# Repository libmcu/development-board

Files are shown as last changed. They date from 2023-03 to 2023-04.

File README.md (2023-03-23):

[한국어](./README_kr.md)

[https://libmcu.org/madi](https://libmcu.org/madi)

Boards produced by libmcu are divided into core boards and extension boards.

Several types of core boards are manufactured in the same form factor,
30x21.59mm long. Because data communication and debugger connection are
possible through the Type-C USB port of the core board, the core board by
itself can fully play the role of a development board.

Extention board is a board to which various sensors and functions are added.
A suitable core board can be attached/detached to the extension board.

For specifications, please refer to [the developer
documentation](https://docs.libmcu.org/boards/index.html).
[SDK](https://github.com/libmcu/MADI) and [getting started
guide](https://docs.libmcu.org/quickstart/index.html) are for you to get
started easily.

## Core Boards
Currently, there are three types of core boards using
[ESP32S3](https://docs.libmcu.org/boards/esp32.html#esp32-libmcu),
[STM32G4](https://docs.libmcu.org/boards/stm32.html#stm32-libmcu), and
[nRF52840](https://docs.libmcu.org/boards/nrf52.html#nrf52-libmcu).

## Extension Boards
Working on it.

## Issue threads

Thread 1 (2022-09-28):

USB-C 포트에 JTAG 핀을 추가하라

onkwon, 2022-09-28:
- SWDIO, SWCLK, SWO, NRST 핀 빼기
- ESP32 의 경우 SWD를 지원하지 않음
  - TMS(SWDIO)와 TCLK(SWCLK) + TDI, TDO 핀을 빼야함

## 참고자료
### USB 일반
- [USB2 사양](https://www.usb.org/document-library/usb-20-specification), [USB3.1 사양](https://manuais.iessanclemente.net/images/b/bc/USB_3_1_r1.0.pdf), [USB4 사양](https://www.usb.org/document-library/usb4r-specification)
- https://www.usb.org/sites/default/files/USB_TCPCI_R2_V1p3_30122_CLEAN.pdf
- https://www.usb.org/sites/default/files/USB%20Type-C%20Spec%20R2.0%20-%20August%202019.pdf
- https://en.wikipedia.org/wiki/USB-C
- https://www.ti.com/lit/wp/slyy109b/slyy109b.pdf
### Debug Accessory Mode
- https://hackaday.com/2022/02/24/an-unbusy-usb-c-port-doubles-up-for-jtag-programming/
- https://threadreaderapp.com/thread/1495860045728395278.html
### Alternate Mode(SBU 기반)
- https://www.ti.com/lit/wp/slly021/slly021.pdf
- https://forum.contextualelectronics.com/t/debugging-through-a-usb-type-c-connector-only/4615
- https://chromium.googlesource.com/chromiumos/platform/ec/+/refs/heads/release-R67-10575.B/board/servo_micro/ccd.md
### Type-C
- https://www.embedded.com/usb-type-c-and-power-delivery-101-ports-and-connections/

Wizmik187, 2022-09-28:
위 자료에 따르면 코어보드에 아래와 같은 OPAMP 회로, AND gate, MUX 회로가 들어가야 합니다.
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

현실성이 좀 없다는 생각이 드네요.

Wizmik187, 2022-09-28:
SBU1, SBU2 핀이라고, Audio accessary 를 위한 핀이 있기는 한데 이 2핀을 뺄 수는 있을 것 같아요. 검토 해보고 알려드리죠.

onkwon, 2022-09-28:
위 자료에서도 그랬듯이 코어가 아니라 중간에 어댑터 보드를 만들어 넣어야 하지 않을까요?

Wizmik187, 2022-09-28:
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
요런 형태로 확인됩니다.

코어보드의 SWD 핀들을 일반적인 USB host에 연결했을 때, 영향이 없도록하기 위해서. DAP 모드에 들어갔을 때만 SWD 핀들이 USB C 핀에 연결되게 하기 위함.

onkwon, 2022-09-28:
아, USB로부터 SWD 핀에 데미지가 갈까봐 있는거군요.

Wizmik187, 2022-09-28:
https://forum.contextualelectronics.com/t/debugging-through-a-usb-type-c-connector-only/4615
https://www.sparkfun.com/products/retired/14746

SBU 핀을 통한 디버깅 (구글 크롬 OS에서 사용했다고 함)

Wizmik187, 2022-09-28:
SWDIO
SWCLK
요 두핀만 빼도 디버깅 하는데 문제는 없을까요?
리셋핀이 없을 때 불편하다던가 하는..

onkwon, 2022-09-28:
SWDIO, SWCLK, SWO, NRST 네 핀 모두 있으면 가장 좋긴하죠.

리셋은 실제로 SWD 만으로 가능한데, "connect under reset" 를 지원해야 할 경우 문제가 있을지도 모르겠어요.

그래서 최선은 4핀 모두, 차선은 SWDIO, SWCLK, SWO 3핀, 정 안되면 SWDIO, SWCLK 두핀으로 가면 좋을 것 같아요.

onkwon, 2022-09-28:
위 자료와 USB 사양을 읽어보고 있는데요,

SuperSpeed 를 사용하지도 않고 USB4 기능을 사용하지도 않으니 호스트에서 RX 핀을 건드릴 일이 없을 것이고 그럼 SWD 핀에 데미지가 갈 일도 없을 것 같습니다. 그러니까 자료에 있는 추가 회로를 생략하고 어댑터 보드만 추가하는 방향으로 가는 것도 괜찮은 방법일 것 같습니다.

Wizmik187, 2022-10-10:
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

- RX 4핀에 디버깅 핀 할당
- SBU1, 2 핀으로 어댑터보드 방향 알려주기 (LED 연결)

onkwon, 2022-10-10:
[USB Type-C 스펙](https://www.usb.org/sites/default/files/USB%20Type-C%20Spec%20R2.0%20-%20August%202019.pdf) Appendix. B 절을 읽은 내용을 요약하면:

- Debug Accessory Mode 로 들어가려면 CC 두 핀 모두 풀업이거나 풀다운이어야 함
- 문제는 Type-C 케이블에 CC 라인이 들어가 있지 않음
- 따라서 직접 연결하거나 captive 디바이스여야 함
- 아래 그림처럼 노란색 핀은 자유롭게 사용할 수 있음
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

그래서 제 생각을 정리하면:
- 우리는 어댑터 보드를 사용하므로 케이블 문제는 고려사항이 아님
  - 개발보드 - 어댑터보드 - PC 직접 연결하기 때문
- 위 그림의 노란색 핀을 자유롭게 사용할 수 있으므로 커넥터 방향에 자유로울 수 있도록 여분의 tx/rx 핀을 모두 활용하면 어떨까 싶어요
- 그리고 사실 개발보드와 어댑터보드는 핀을 모두 연결하더라도 어댑터보드에서 PC로 가는 핀은 데이터 핀만 연결해도 상관없잖아요?
- 이런식으로 연결해서 사용하면 될 것 같은데, 어떻게 생각하시나요? : https://www.reddit.com/r/embedded/comments/syihdl/comment/hxy10b9

Wizmik187, 2022-10-10:
https://itecnotes.com/electrical/electronic-usb-c-debug-accessory-mode-and-usb-2-0/

onkwon, 2022-10-10:
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

- 우리는 그림과 같은 구성이니까 존이 공유한 링크에서 말한 우리 Core 보드(TS)는 compliant final product 가 될거고,
- 어댑터보드의 왼쪽(TS와 연결되는 쪽)은 DTS 역할로 CC 라인을 조작
- 어댑터보드의 오른쪽(PC와 연결되는 쪽)은 다시 CC 라인을 조작하지 않는 정상적인 포트로 사용하면 되지 않을까요?
  - 이 때 굳이 다른 JTAG 라인을 연결할 필요도 없을 것 같고요. 이 포트는 USB2.0 기능만 사용할테니 D+ D-만 연결해도 될 것 같아요

제가 뭔가 놓친게 있을까요?

Wizmik187, 2022-10-11:
DTS (어댑터 보드) 에서 CC 라인 2개를 모두 Pull-up 하면 TS (코어보드) 에서 DTS 가 연결되었다는 것을 인식하고, MUX 등을 이용하여 안쓰는 USB C 커넥터 핀에 SWD 핀이 연결되도록 하는 것이 정석일것 같습니다.  (제일 처음 봤던 아래 링크 문서처럼)
(https://hackaday.com/2022/02/24/an-unbusy-usb-c-port-doubles-up-for-jtag-programming/)

단, 이 경우엔 MUX  등의 불필요한 부품이 코어보드에 추가 되는 것이 문제이죠.

DAM 에서는 Host (PC 등)에 연결되는 상황을 정의하지는 않는 것 같아요. 사용자 몫인 것이죠.
DTS 없이 TS(코어보드) 를 바로 Host에 연결했을 때가 걱정되는 것이죠.

- MUX 등 부품을 추가하여 안전하게 간다.
- 왠만해서는 RX 핀을 안건드릴 거라고 가정하고, RX 핀에 SWD 핀을 할당한다.
- reversible 을 위하여  RX, TX 핀에 SWD  핀을 할당한다. 단 이 경우 위보다 문제가 생길 확률이 높음.

Wizmik187, 2022-10-11:
일반적인  USB C 케이블은 CC 핀 하나가 케이블에서 풀다운 되어 있기 때문에, CC 핀 2개 모두가 풀업되는 경우는 없습니다.
DTS (어댑터 보드)에서 DAM 을 위해 CC 핀 2개를 강제로 풀업시켜서, 지금 연결되는게 DTS이다 라고 TS에게 알려주는 것이죠.

Wizmik187, 2022-10-11:
USB 3.0 이상에서 추가되는 rx 핀이 host에 연결되지 않도록 USB 2.0 케이블만 사용하도록 가이드를 주는 방법이 가장 현실적일것 같습니다.

Wizmik187, 2022-10-12:
아래와 같은 방법 어떠신가요.

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

1. 아날로그 스위치 IC 를 사용하여 nRESET, SWDIO, SWO, SWCLK 4핀을 on / off 할수 있게 합니다.
2. USB C 커넥터의 SBU2 핀을 아날로그 스위치의 Control 핀에 연결하고,
3. 어댑터 보드가 꼽히면 SBU2 핀에 5V를 공급하게 해서 아날로그 스위치 IC를 on 시켜서 4핀을 연결시킵니다.

SBU1 SBU2 핀은
https://www.usb.org/sites/default/files/USB%20Type-C%20Spec%20R2.0%20-%20August%202019.pdf
위 링크의 아래 절 참조
- 4.3 Sideband Use (SBU)
- Table A-1 USB Type-C Analog Audio Pin Assignments

Audio Adapter Accessory Mode 에서 MIC / AGND 로 쓰이므로 host 에서 별다른 영향을 주지는 않을 것으로 보입니다.

onkwon, 2022-10-13:
좋습니다! 말씀하신대로 하면 핀 대칭도 유지할 수 있겠네요. 👍

onkwon, 2022-10-13:
그런데 다른 회로들을 좀 찾다보니 SWO 보다 Vref 핀을 빼는게 정석(?)인가 싶네요?

Wizmik187, 2022-10-13:
쿤,
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

ESP32 는 JTAG는 지원하는데 SWD를 지원하지 않는다는다네요...

JTAG는 TDI, TDO, TCK, TMS 총 4핀에 reset 까지 5핀이 필요한것 같습니다..

onkwon, 2022-10-13:
네, 이슈 description 에 업데이트 해두었었는데, 앞으로 업데이트할 때 따로 알림을 해야겠네요.

저는 커넥터 좌우 대칭을 유지하고 싶고, 스위치 IC에 여분 핀도 없으니 ESP32 의 경우는 reset 을 빼고 가면 어떨까 싶습니다.

onkwon, 2022-10-13:
핀 아웃은 아래 이미지처럼 하면 어떨까요? 검색해보니 JLink edu mini 와 ULinkPro pinout 이 같더라고요.

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

- https://www.segger.com/products/debug-probes/j-link/models/j-link-edu-mini/
- https://developer.arm.com/documentation/101416/0100/Hardware-Description/Target-Interfaces/Cortex-Debug--10-pin-

onkwon, 2022-10-18:
존, 이건 정리된 것 같으니 이슈 닫을게요. 필요하시면 다시 열어주세요.

Closed 2022-10-18.

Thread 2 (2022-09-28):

코어보드의 소자 소비전류, 정확도, 가격을 파악하라

onkwon, 2022-09-28:
- BQ25180YBGR
  - https://www.ti.com/lit/ds/symlink/bq25180.pdf
- TMP103BYFFR
- APA102-2020

onkwon, 2022-10-18:
## BQ25180

### 사양

| FUNC | MIN | TYP | MAX | UNIT |
| ----- | ---- | ----- | ----- | ----- |
| Input Voltage | -0.3 | | 25 | V |
| Voltage | -0.3 | | 5.5 | V |
| Input Current | | | 1.1 | A |
| SYS Discharge Current | | | 1.5 | A |
| Output Sing Current | | | 20 | mA |
| VBAT | 2.2   | | 4.6   | V       |
| VIN    | 2.7    | | 5.5   | V      |
| Tj*     | -40  | | 125  | C       |
| Quiescent Current(VIN) | | 0.75 | 1 | mA |
| Quiescent Current(BAT) | | 4 | 5 | uA |

- Tj*: Operating Junction Temperature Range

### 노트
- 배터리 완전 방전을 방지하기 위해 `CHARGERCTRL1` 레지스터의 `BUVLO` 비트를 설정해야 함
- overvoltage protection 기능도 있음. 입력전압에 대한 상대값이기 때문에 디폴트 유지하기로
- `IBAT_OCP` 레지스터에 배터리 overcurrent 설정할 것
- Safety timer 를 활용하면 사용자에게 알람 줄 수 있음
  - INT 핀 MCU 에 연결했는지 확인
- Thermal protection 기능 좋아 🥹

### 할일
- [ ] 리셋핀을 MCU 에서 빼지말고 BQ25180 TS/MR 핀
활용하면 어떨지
  - 다른 버튼 하나는 MCU GPIO 핀을 연결할 수 있고
  - MCU 뿐만 아니라 시스템 전체가 리셋됨
  - 소비젼류가 늘어나는 문제가 있지만, 저전력이 중요한 제품에서는 해당 기능을 끄는 방법이 있겠음
  - 또 하나의 문제는 300ms latency 가 발생하는 건데, 리셋은 보통 개발단계에서만 사용될 것이기 때문에 괜찮지 않을까 싶음
- [ ] 배터리 용량 결정하고, 충전 및 방전 시간 명시

Wizmik187, 2022-10-19:
@onkwon 그럼 MCU 리셋 버튼이 없을텐데요? 괜찮을까요?

onkwon, 2022-10-19:
버튼에 TS/MR 핀을 연결하고

- 300ms 이상 누르면 MCU soft reset
- 5초 이상 누르면 시스템 전체 hard reset

이렇게 가면 어떨까요?

Wizmik187, 2022-10-19:
이해했습니다. 좋은생각인 것 같아요. 단 펌웨어 드라이버에서 버튼 컨트롤하는 부분이 들어가야할것 같습니다. 데이터시트를 좀더 읽어보고 회로 결정할게요.

onkwon, 2022-10-19:
> [...] 펌웨어 드라이버에서 버튼 컨트롤하는 부분이 들어가야할것 같습니다. [...]

어떤 컨트롤을 말씀하시는 건가요? 아래 이미지처럼 기존 회로에서 다른 변경없이 MR 핀에 nRESET 만 엮어주면 되지 않나요?

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

onkwon, 2022-10-23:
@Wizmik187
현재 MR 핀을 어떻게 연결할지 두가지 안이 있는데요:
1. *사용자 버튼*에 연결(MCU GPIO 핀과 함께 연결)
2. *Reset 버튼*에 연결

저는 2번을 선호해요. 제 논리는 아래와 같습니다:
- *MCU 리셋* 이든 *시스템 리셋* 이든 리셋은 리셋 버튼으로 이루어져야 한다고 봄
  - 시스템 리셋을 위해 *리셋 버튼*이 아니라 *사용자 버튼*을 누른다는 게 직관적이지 않음
  - MR 핀의 시스템 리셋과 *사용자 버튼*의 custom 기능이 충돌할 수 있음
    - 이런 사용자 고려사항들은 없을수록(단순할수록) 좋다고 보임
    - 그리고 충돌을 피하기 위해 시스템 리셋의 홀드시간을 늘리는 것도 사용자 편의를 크게 감수해야 함
- *사용자 버튼*은 이미 MCU 의 GPIO 에 연결되어 있으므로 MR 핀으로 입력받은 short/long 버튼은 기능적으로 의미가 있어보이지 않음

Wizmik187, 2022-10-24:
쿤 말 듣고, Reset 핀에 연결하는 것도 나쁘지 않을 것 같다고 설득되긴 했는데요,

Reset 버튼이나 사용자 버튼에 MR핀을 같이 연결하기에는 아래와 같은 문제가 있을 것 같습니다.
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

데이터시트 그림에 따르면 bq25180이 MR 핀으로 계속 pulse 를 만들고 이 펄스로 버튼 누르는 시간을 감지하고 있는 것 같습니다. 즉 Reset 핀이나 GPIO에 이 펄스가 입력되면 MCU 오동작이 예상됩니다.

따라서 일단은 GPIO와 같이 물리는건 포기하고 처음에 얘기했던것 처럼 아래와 같이 저항으로 선택할 수 있게 하는게 어떨까 해요. (default 는 GPIO 연결)
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

onkwon, 2022-10-24:
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

타이밍 차트 표현이 헷갈리게 해놓은 것 같아요. 그런데 제가 이해하기론, 전력소비를 줄이기 위해 200ms 주기로 센싱한다는 것 같습니다. 그래서 여전히 2번을 주장해봅니다 😅

Wizmik187, 2022-10-25:
네 쿤 말씀이 맞는 것 같습니다. 그런데 추가로 걱정되는게 생겼습니다.

일단 기본적으로 Reset 핀에는 풀업이 달려있기 때문에(ESP의 경우  autoreset을 위해 1uF Cap 도 부착) , reset 핀을 MR 핀에 연결하는 순간 MR 핀에도 풀업이 달리게 되고, 이 경우 TS (NTC 연결하여 온도 측정) 하는 기능이 제 동작을 못할 수 있습니다.

최악의 상황에는 External NTC Monitoring (TS) 기능을 disable 해야 할수도 있을것 같습니다.

요 회로는 한번 TI community에 올려서 TI 쪽에 체크를 받아볼게요.

Wizmik187, 2022-10-25:
생각해보니 10KR풀업 저항과 10K NTC 가 달리는 순간 Reset 핀이 3.3/2 V 이 될 거고 리셋핀 동작이 제대로 안되겠네요.
reset 핀과 NTC와 같이 사용하기는 어려울것 같습니다.

쿤 말씀대로 0R 을 추가하는게 현실적이겠네요.

onkwon, 2022-10-25:
네, 내부 온도센서가 있기 때문에 제 생각에는 외부 온도센서를 붙이는 일이 보통은 없을 것 같거든요. 그래서 그런 케이스를 그렇게 비중을 두고 고려할 필요가 있을까 싶어요. 어떻게 생각하세요?

Wizmik187, 2022-10-25:
네 좋습니다.
짧게 누르면 MCU reset 길게 누르면 전체 하드웨어 리셋이 일관성이 있어서 좋을것 같습니다.

Ti support 에 문의했으니 회로적으로 문제 없는지 보겠습니다.

https://e2e.ti.com/support/power-management-group/power-management/f/power-management-forum/1164580/bq25180-able-to-place-pullup-resistor-to-mr-pin

onkwon, 2022-10-29:
뒷북이긴 한데, M5Stack 에는 어떤 IC를 썼나 궁금해져서 찾아봤습니다. [AXP192](https://github.com/m5stack/M5-Schematic/blob/master/Core/AXP192%20Datasheet_v1.1_en_draft_2211.pdf) 을 사용했는데, 가격이 깡패입니다: $0.35
따로 레귤레이터가 필요하지도 않구요.

onkwon, 2022-11-02:
정리된 내용이므로 이슈 닫겠습니다.

Closed 2022-11-02.

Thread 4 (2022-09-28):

코어보드 사양을 결정하라

onkwon, 2022-09-28:
## MCU
- [x] ESP32
  - ESP32-WROOM-32E-N4
  - [ESP32-WROOM-32E Datasheet](https://www.espressif.com/sites/default/files/documentation/esp32-wroom-32e_esp32-wroom-32ue_datasheet_en.pdf)
  - [ESP32 Series Datasheet](https://www.espressif.com/sites/default/files/documentation/esp32_datasheet_en.pdf)
  - https://www.espressif.com/en/products/modules
  - 안테나 때문에 비용에 따라 ESP32-WROVER-IE 를 고려해보는 것도
  - 100개 기준 $2.85
    - https://lcsc.com/product-detail/WiFi-Modules_Espressif-Systems-ESP32-WROOM-32E-N4_C701341.html
- [ ] ESP32-C3
- [ ] STM32
  - STM32G0 vs STM32G4
- [x] nRF52840
- [ ] nRF9160

## 디버깅 포트
SWDIO, SWCLK 두 핀으로 플래시를 비롯한 디버깅 기능은 문제없이 사용할 수 있음. 하지만 "connect under reset"(SWD 핀을 다른 용도로 사용할 경우) 를 지원해야 할 경우 문제. 이 때는 NRST 핀이 필요함. SWO 는 플러스 옵션.

- [x] SWDIO
- [x] SWCLK
- [x] SWO
- [x] NRST

## 온도센서
대게의 경우 SoC 에 내장된 온도센서가 하나씩 있음. ESP32 에만 없음(ESP32 C3/S3 에는 있음)

## 상태 LED

## 소비전류
TBD

## PMU
- [ ] BQ25180YBGR
  - https://www.ti.com/lit/ds/symlink/bq25180.pdf
- [ ] AXP202
  - https://dl.linux-sunxi.org/AXP/AXP202%20Datasheet_v1.0_en.pdf
  - https://github.com/tuupola/axp202
- [ ] AXP192
  - https://github.com/m5stack/M5-Schematic/blob/master/Core/AXP192%20Datasheet_v1.1_en_draft_2211.pdf

## 주변장치
- [x] ADC
- [x] UART
- [x] SPI
- [x] I2C
- [x] Timer(PWM)
- [ ] USB
- [ ] DMA
- [ ] QSPI

## 핀아웃(폼팩터)
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

### USB C

반대 방향과 대칭이므로 윗줄만 나타냄

| GND | TX1+ | TX1- | VBUS | CC1 | D+ | D- | SBU1 | VBUS | RX2- | RX2+ | GND |
| ----- | ----- | ----- | ----- | ----- | ---- | ---- | --- | ----- | ----- | ----- | ------ |
|          |           |          |           |           |        |          |  Target VCC  |          | SWDIO | SWCLK |    |

## ESP32 Core 보드 사양

| Name | Desc. |
| ------ | ----- |
| ESP32-WROOM-32E-N4(ESP32-D0WD-V3) | 240MHz dual core, 600 DMIPS, 520KB SRAM, Wi-Fi, BLE |
| Flash | 4MB |
| PSRAM | - |
| Input Voltage | 5V @ ?mA |
| Interface | TypeC |
| LED | Blue power indicator light |
| Button | Reset button, User button |
| PMU | BQ25180YBGR |
| USB Chip | CH9102F |
| Lithium Battery | ?mAh @ ?V |
| Antenna | 2.4GHz PCB antenna |
| Operating temperature | -40 ~ 85 (다른소자 확인필요) |
| Net Weight | |
| Gross Weight | |
| Product Size | |

onkwon, 2022-09-28:
언급된 MCU 중에 ESP32 에만 USB 가 없습니다.
uart_to_usb 칩은 외부로 빼는 방법이 있겠지만, 다른 보드와의 호환성이나 사용자 편의를 생각하면 내장하는 게 좋을 것 같습니다.

onkwon, 2022-10-18:
@Wizmik187 ESP32 HSPI vs VSPI 에서 저는 VSPI 핀만 뽑아도 충분할 것 같아요.

- 두개다 하드웨어 SPI 이고
- HSPI 가 JTAG 핀과 겹치기도 하고요

onkwon, 2022-10-18:
그리고 존이 말씀하셨듯이 주변장치 핀아웃은 "가능한" 모든 보드에서 호환되는 방향으로 가면 좋을 것 같아요.

Wizmik187, 2022-10-24:
아래 링크에 따르면 VSPI HSPI 간 속도차이가 있는 것 같고 HSPI 가 더 빠를것 같긴 한데요. 그래도 VSPI 를 빼는게 괜찮을까유?

https://www.youtube.com/watch?v=UUsP7u4vkN0&ab_channel=CoherentWave

Wizmik187, 2022-10-24:
- USB 다이오드 추가
- 커넥터 1x8 로 2개로 변경
- 바텀면 있는 소자를 전부 탑면으로 옮길 수 있는지 검토

onkwon, 2022-10-24:
VSPI 나 HSPI 나 기능상으로는 별다른 차이가 없어서 뭘 사용해도 상관없을 것 같은데, HSPI 가 JTAG 핀과 겹치니 VSPI 사용하면 좋을 것 같습니다.

Closed 2022-11-07.

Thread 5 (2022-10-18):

어댑터 보드를 설계하라

onkwon, 2022-10-18:
- 코어보드 디버깅을 용이하게 하는 추가 개발보드

## Future Work
- [ ] DAP 적용. JLink 와 같은 추가 디버거를 제거

onkwon, 2022-10-28:
GD32, APM32, AT32 시리즈에서 USB 디바이스를 내장하고 128KB 이상의 플래시와 32KB 이상의 SRAM 을 가진 MCU 중에서 재고가 있고 가격이 싼 걸 찾아봄:

- https://www.chipsmall.com/So/apm32f.html
- https://www.chipsmall.com/So/gd32f.html
- https://www.chipsmall.com/So/at32f.html

찾아본 것 중에는 APM32F103C8T6 이 가장 저렴한데, 메모리가 20K라 가능할지 모르겠음.
그리고 재고와 가격이 사이트마다 달라서 신뢰하기가 어려움

- [AT32F403ARCT7](https://www.chipmall.com/search?q=at32f403a&qty=&page=1)
  - 100개 기준 $2.33
- [APM32F103C8T6](https://www.chipsmall.com/Products/APM32F103C8T6_Geehy_20383477.html)
  - 100개 기준 $1.34
- [GD32F103C8T6](https://www.chipmall.com/search?q=gd32f103&qty=&page=1)
  - 100개 기준 $2.2

onkwon, 2022-10-28:
아래 칩 중 하나를 사용하면 어떨까 싶습니다. 가격이나 수급에 문제가 있다면 다른 대안을 또 찾아봐야겠지만.

- [GD32F103CBT6](https://www.gigadevice.com/products/microcontrollers/gd32/arm-cortex-m3/mainstream-line/gd32f103-series/gd32f103cbt6/)
- [GD32F103RBT6](https://www.gigadevice.com/products/microcontrollers/gd32/arm-cortex-m3/mainstream-line/gd32f103-series/gd32f103rbt6/)
- [GD32F103TBU6](https://www.gigadevice.com/products/microcontrollers/gd32/arm-cortex-m3/mainstream-line/gd32f103-series/gd32f103tbu6/)
- [GD32F103VBT6](https://www.gigadevice.com/products/microcontrollers/gd32/arm-cortex-m3/mainstream-line/gd32f103-series/gd32f103vbt6/)

onkwon, 2022-10-31:
## APM32 관련 노트
- 가격이나 용도를 생각하면 APM32E103Cxx6 이 적합해보이지만
  - 하위 모델은 일단 재고를 못찾겠음
- 재고와 추가적인 용도(Core 보드)에 함께 사용할 걸 생각하면 APM32E103RET6 가 괜찮은 선택으로 보임
- APM32F와 APM32E 차이점은 미세공정이 적용되었다고
  - 전류 소비가 절반?!이나 줄고
  - 최대 클럭은 1.7배 빠르다고
  - 그리고 FPU가 있음
- 국내 유통사: http://itechcorp.co.kr/

Wizmik187, 2022-11-03:
와우! 국내 유통사 까지 있네요. 좋습니다.

onkwon, 2022-11-03:
월요일에 국내 유통사로부터 샘플 3개 받기로 했습니다.
처음에 10개로 얘기가 됐었는데, 회사 정보가 없어서 그런지 소극적으로 대응하시네요.
첫 구매는 MOQ 250개 라고 합니다. 견적서를 아직 안보내줘서 정확한 가격은 모르겠구요.
대략 들은 가격은 $1.65 입니다.
아, APM32E103CET6 로 얘기가 됐습니다. LQFP48 입니다.

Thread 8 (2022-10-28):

회로를 리뷰하라

onkwon, 2022-10-28:
올려주신 회로보고 몇가지 의문사항 남겨요

## 1. 사용자 버튼은 빠지는 건가요?
공간상 넣기가 곤란하다면 스루홀? 형태로 하나 빼놓는 건 어떨까요?
## 2. 4.4v ~ 4.9v 범위의 전압을 VSYS 핀으로 내보내게 되는데 쓸모가 있을지 의문입니다
- VIN 을 넣는건 어떨까요?
- 지금은 전원 유입될 수 있는 곳이 USB 포트밖에 없어서 VIN이 있으면 활용 여지가 있을 것 같습니다
## 3. 아래 회로에서 SYS는 output 인데 input 심볼이 있는 것 같아요
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

Wizmik187, 2022-10-28:
1.
사용자 버튼은 바텀면 중앙에 위치시켰습니다. 자리만 있고 부품 실장은 안하려고 합니다. (SMT를 탑면만 하여 비용 절감)
사용자가 필요하다면 솔더링 하여 사용하는 것으로 생각하고 있어요.
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

바텀면 중앙이 버튼 위치로는 자연스러워서 위와 같이 했는데, 고민중이긴 합니다. 리셋버튼이랑 대칭되게 탑면에 배치할 수는 있을것 같아요.

마찬가지로 NTC도 자리만 있고 필요하다면 솔더링 하여 사용하도록 가이드 하려고 합니다.

2.
여러가지 상황을 고려했는데요, 일단은 헤더핀으로 사용하는 센서나 기타 주변기기에
전원을 공급해야 할때 SYS 전원을 사용할 수 있습니다. 3.3V LDO 는 최대 전류가 300mA라서 애매한 경우가 생길 수 있습니다. 3.3V 외의 다른 전압 (예를 들면 1.8V나 12V) 을 만들어야 할 때도, 3.3V 를 입력으로 넣는 것보다 SYS를 넣는 것이 더 효율적일것 같아요.

또한 외부에서 전원을 공급받을 때도, SYS핀을 통해 공급받는 것이 각종 bq25180 Safety feature 를 사용할 수 있을거라는 생각이 들어요.
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
위와 같이 세팅하면, VIN (USB 전원)이 존재해도 쫑안나고 안전하게 SYS핀을 통해 전원을 공급받을 수 있을듯 합니다.
(SYS 핀으로 전원을 공급하고 싶을 때는 SYS off floating 으로 세팅하도록 가이드)

3.
수정하였습니다!

onkwon, 2022-10-28:
## 1
- 저도 의견을 보태자면, 버튼은 탑면에 배치하고 실장하면 좋을 것 같습니다
- 그리고 배터리를 부착하게 되면 위치가 아마도 현재의 사용자 버튼 위치가 되지 않을까요?
- 그런 점에서 NTC 위치도 구석으로 좀 밀면 어떨까 싶기도 하고요

## 2
좋습니다. 👍 `SYS` 핀에 그런 기능이 있는지 몰랐네요. 하나 추가적으로 드는 의문이

- `SYS_MODE` 가 `00` 인 상태(Normal Operation)에서 SYS 로만 전원이 공급되는 경우에는 문제가 없을 것 같은데
- `SYS_MODE` 가 `00` 인 상태(Normal Operation)에서 IN 으로도 전원이 공급되고 SYS 로도 전원이 공급되는 경우에는 어떻게 동작하게 될까요?

왜냐하면 상시전원 제품이라고 가정하고, 전원을 넣은 상태에서 디버깅을 위해 USB 를 꽂아도 괜찮을까 라는 생각이 들었어요.

## spec.
spec. 정리를 위해 아는 것만 요약해보면

### 전원
- IN 입력 전압은 2.7 ~ 5.5VDC(최대값은 -0.3 ~ 25VDC)
- IN 최대 허용 전류는 1.1A
- [출력] SYS 최대 허용 전류는 1.5A
  - 순간(<20ms) 최대 허용 전류는 2.5A
- [입력] SYS 최대 입력 전압은 1.8 ~ 5.5VDC

### 온도
| 소자 | 온도(도섭씨) |
| ---- | ----------- |
| TCR3RM33A | -40 ~ 85 |
| BQ25180 | -40 ~ 125 |
| SN74LV4066ARGYR | -40 ~ 85 |
| CP2102N | -40 ~ 85 |
| KUSBX-SMT-CS2-B30TR | -30 ~ 85 |
|  ESP32-WROOM-32E | -40 ~ 85 |

PCB, 커넥터, 패턴등이 어떻게 되는지 모르지만, 일단은 권장 온도는 -30 ~ 85 도 라고 볼 수 있겠네요.

Wizmik187, 2022-10-31:
> * `SYS_MODE` 가 `00` 인 상태(Normal Operation)에서 SYS 로만 전원이 공급되는 경우에는 문제가 없을 것 같은데
> * `SYS_MODE` 가 `00` 인 상태(Normal Operation)에서 IN 으로도 전원이 공급되고 SYS 로도 전원이 공급되는 경우에는 어떻게 동작하게 될까요?

사실 이부분은 저도 추측으로 괜찮을 거 같다 라고 생각만 드는거라서, 정확히는 이렇게 사용해도 되는지 TI 쪽에 문의를 해보겠습니다.

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

일단 제 판단에는, FET로 전류제어하는 기능이 있기 때문에, SYS에 전원이 있는 상태에서 IN에 5V가 들어와도 어느 한쪽으로 스펙이상의 전류가 흘러서 IC가 망가지거나 하는 일은 없을 것 같긴 합니다.

onkwon, 2022-11-16:
더이상 관련 이슈가 없으므로 닫겠습니다.

Closed 2022-11-16.

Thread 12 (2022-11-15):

PMU IC 를 선정하라

onkwon, 2022-11-15:
## 요구사항
- [ ] 리튬 배터리 충전
- [ ] USB 공급전원에서 동작(3V ~ 12V 입력 전압 지원하면 좋음)
- [ ] 최소 300mA 공급, 가능한 800mA 이상
- [ ] lq(대기전류) 낮을수록 좋음. 최소 수십 uA보다 낮아야 함
- [ ] 배터리 잔량 체크
- [ ] MCU 구동을 위한 3.3V 출력

onkwon, 2022-11-23:
결정된 것 같으니 닫겠습니다.

Closed 2022-11-23.

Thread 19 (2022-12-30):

Core-S3 보드 브링업

onkwon, 2022-12-30:
## 점검항목
- [ ] 시리얼 플래시
- [ ] 콘솔
- [ ] LED
- [ ] BQ25180
- [ ] 와이파이
- [ ] 리셋 버튼
- [ ] 사용자 버튼
- [ ] 전원 노이즈
  - [ ] LDO
  - [ ] BMS
- [ ] 전압 레벨
  - [ ] LDO
  - [ ] BMS

onkwon, 2022-12-30:
@Wizmik187 [ESP32](https://github.com/libmcu/development-board/tree/main/core/Core_ESP32-WROOM-32E_PCB) 보드와 S3 보드의 I2C 포트가 다른데 통일하면 좋을 것 같아요.

ESP32 는 GPIO21, 22 사용했고, S3에서는 GPIO17, 18 사용하고 있습니다.

onkwon, 2022-12-30:
핀헤더 텍스트도 추가하는 게 좋을 것 같아요.
리셋버튼이 뭔지 사용자버튼이 뭔지 매번 헷갈리고,
배터리 연결을 위해 `+VBAT` 핀 찾기도 번거로운 것 같아요.

Wizmik187, 2022-12-30:
네 그런데 보드가 작다보니 넣는게 좀 애매하긴 해요. 지저분해보이기도 하고. 최대한 잘 넣어보겠습니다.

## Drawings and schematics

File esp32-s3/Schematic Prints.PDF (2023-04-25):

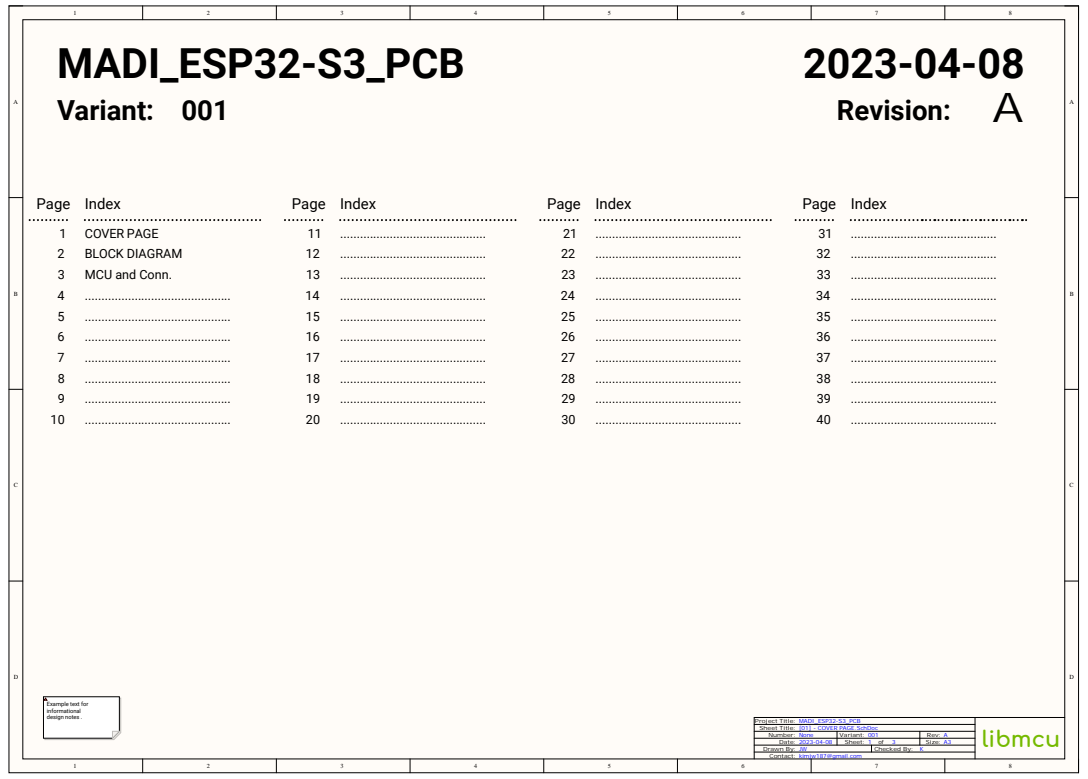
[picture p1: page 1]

Project Title:
Sheet Title: [01] - COVER PAGE.SchDoc

Number: None | Variant: 001 | Rev: A
Date: 2023-04-08 | Sheet: 1 of 3 | Size: A3
Drawn By: JW

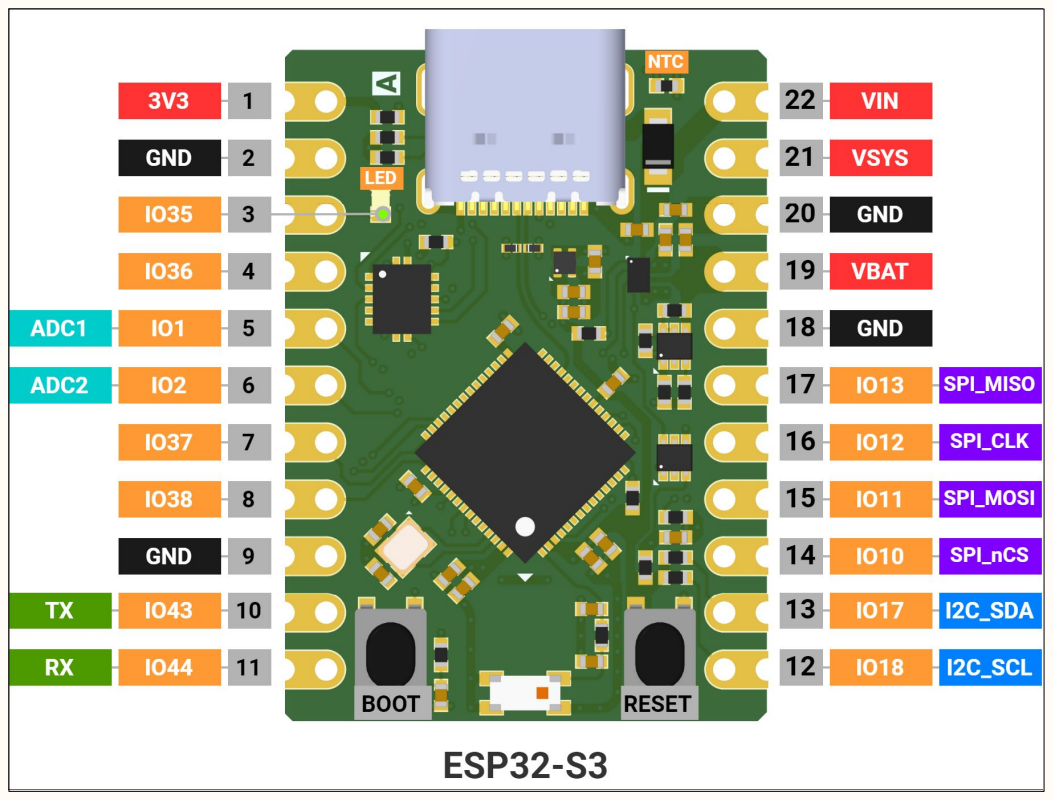
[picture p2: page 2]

Sheet Title: [02] - BLOCK DIAGRAM.SchDoc

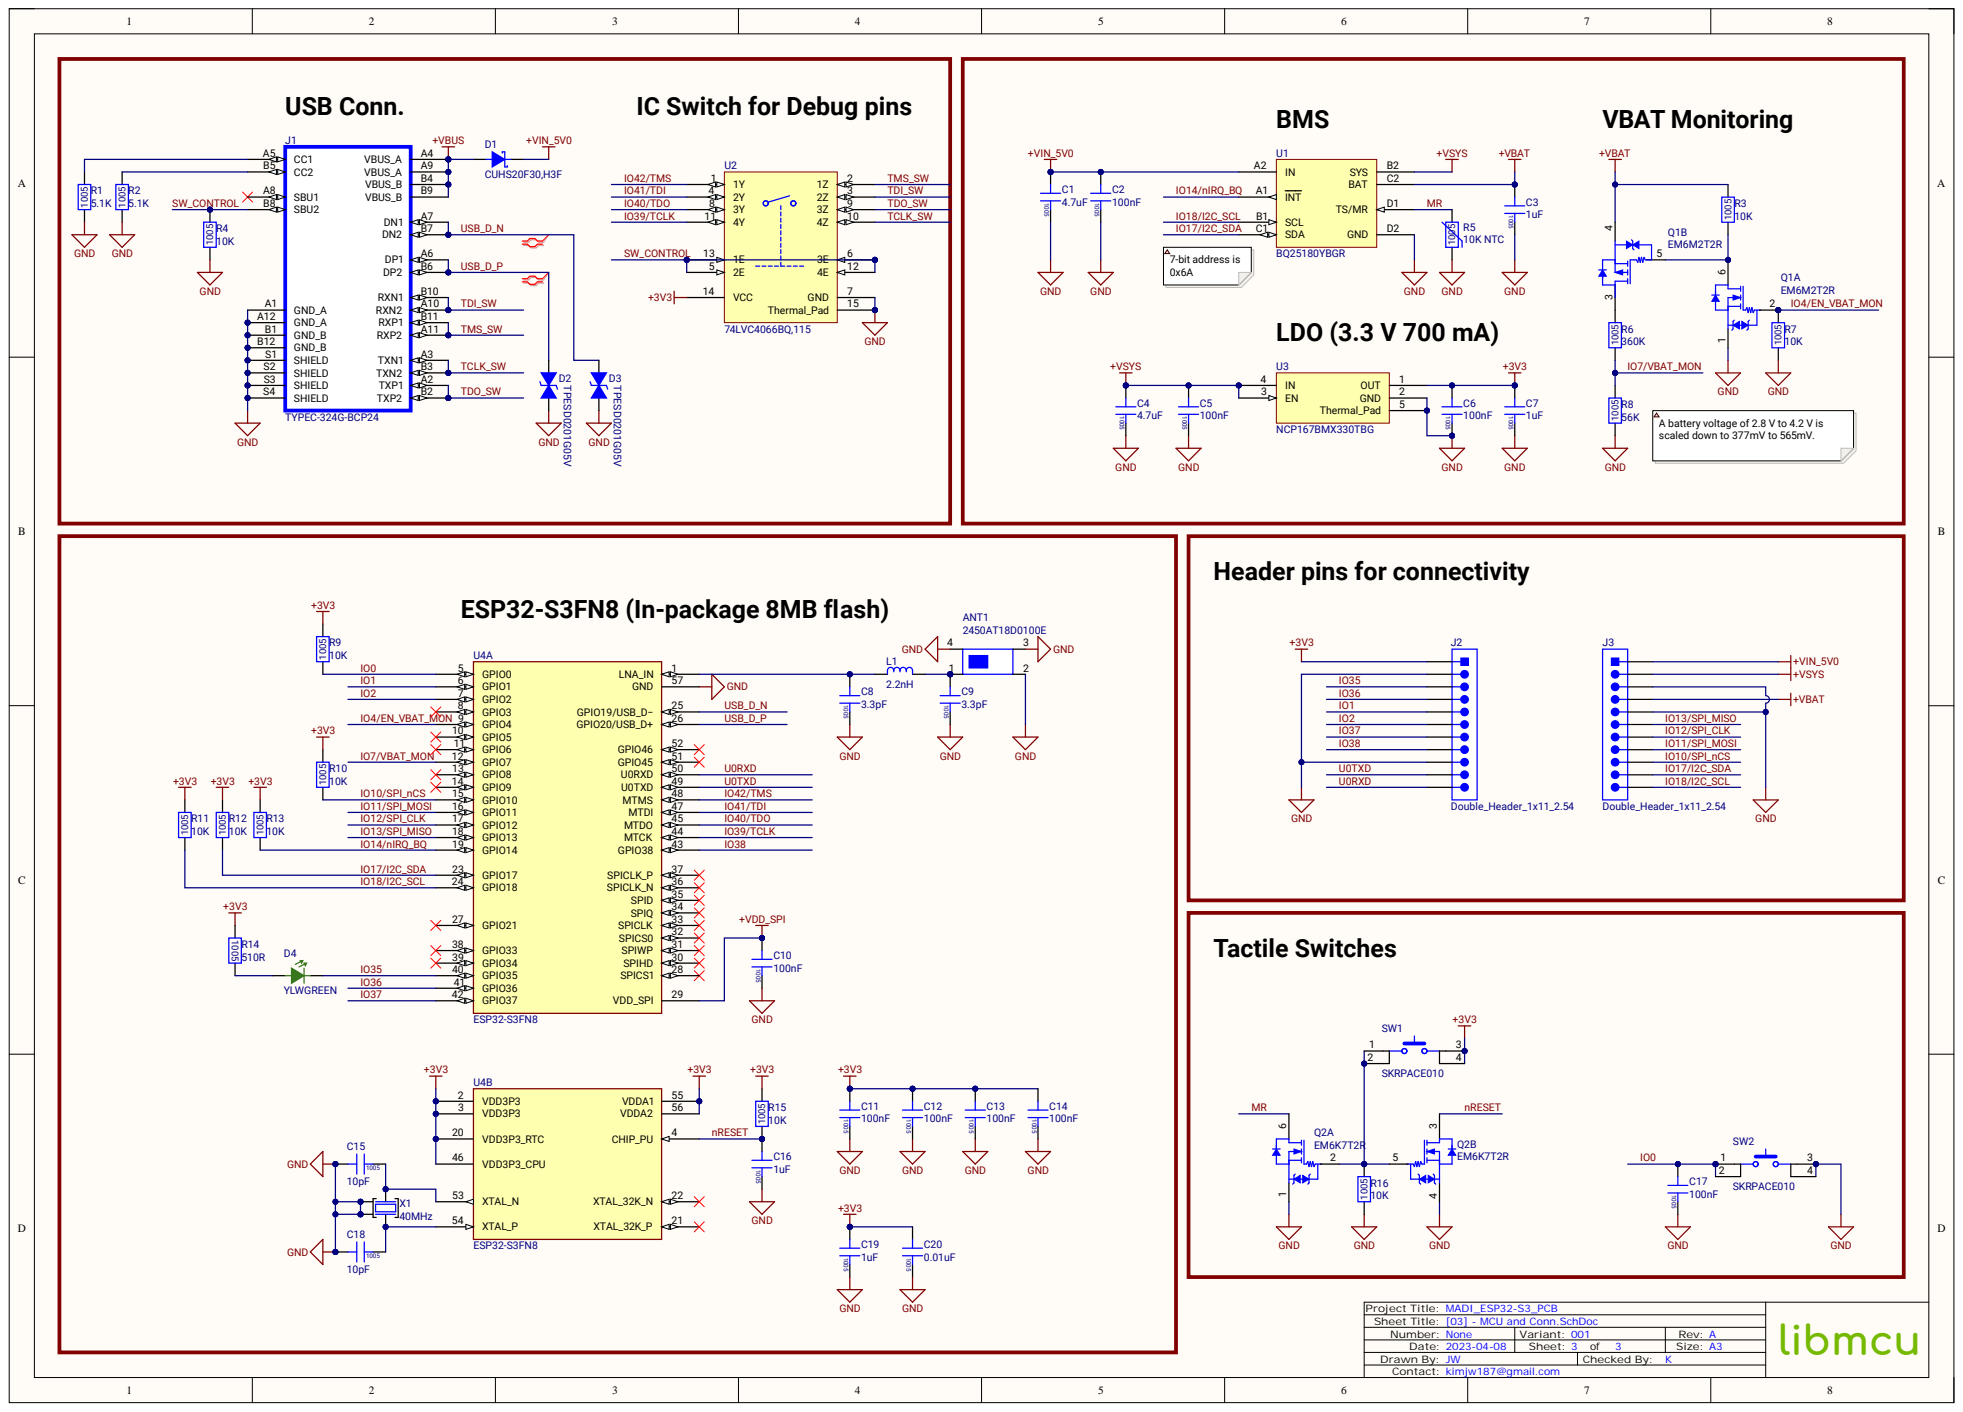
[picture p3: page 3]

A battery voltage of 2.8 V to 4.2 V is
scaled down to 377mV to 565mV.

Header pins for connectivity

Sheet Title: [03] - MCU and Conn.SchDoc

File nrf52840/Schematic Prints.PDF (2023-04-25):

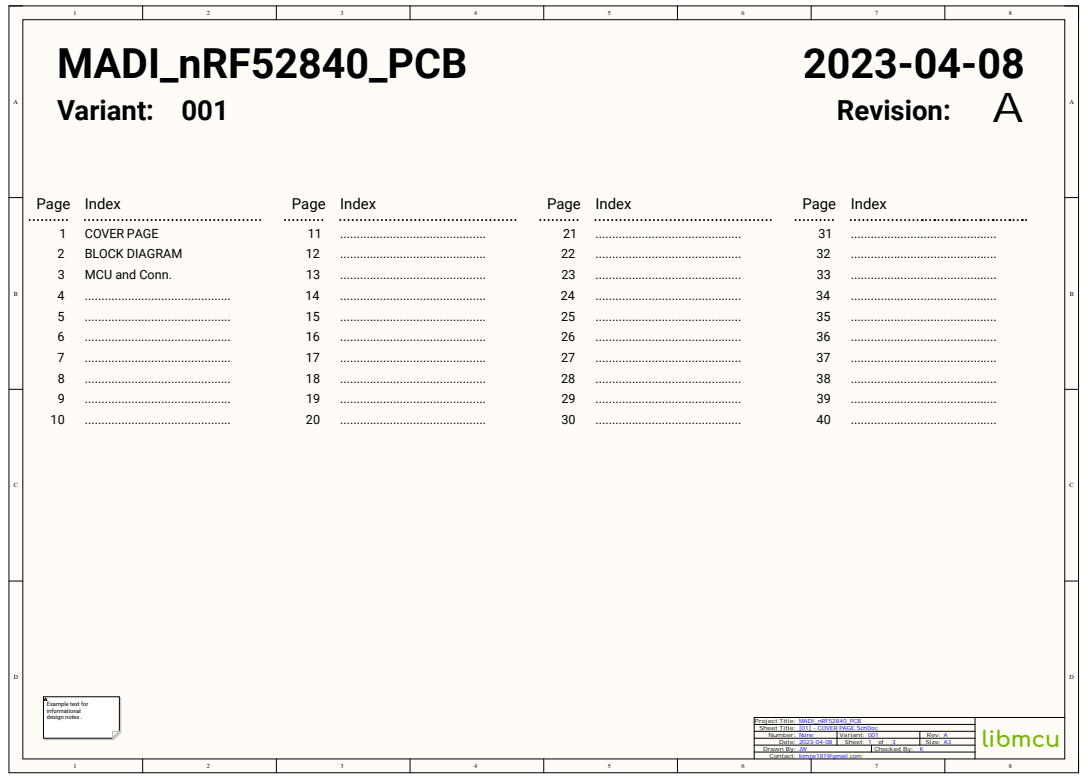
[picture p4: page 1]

Project Title:
Sheet Title: [01] - COVER PAGE.SchDoc

Number: None | Variant: 001 | Rev: A
Date: 2023-04-08 | Sheet: 1 of 3 | Size: A3
Drawn By: JW

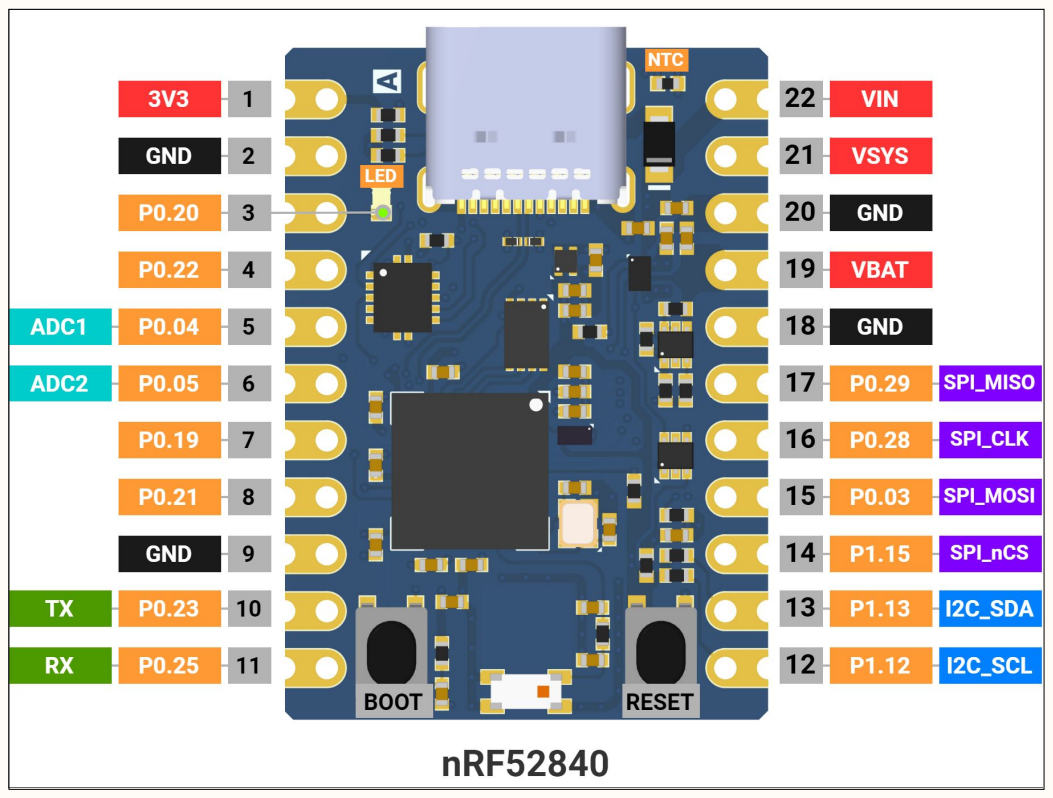
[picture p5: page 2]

Sheet Title: [02] - BLOCK DIAGRAM.SchDoc

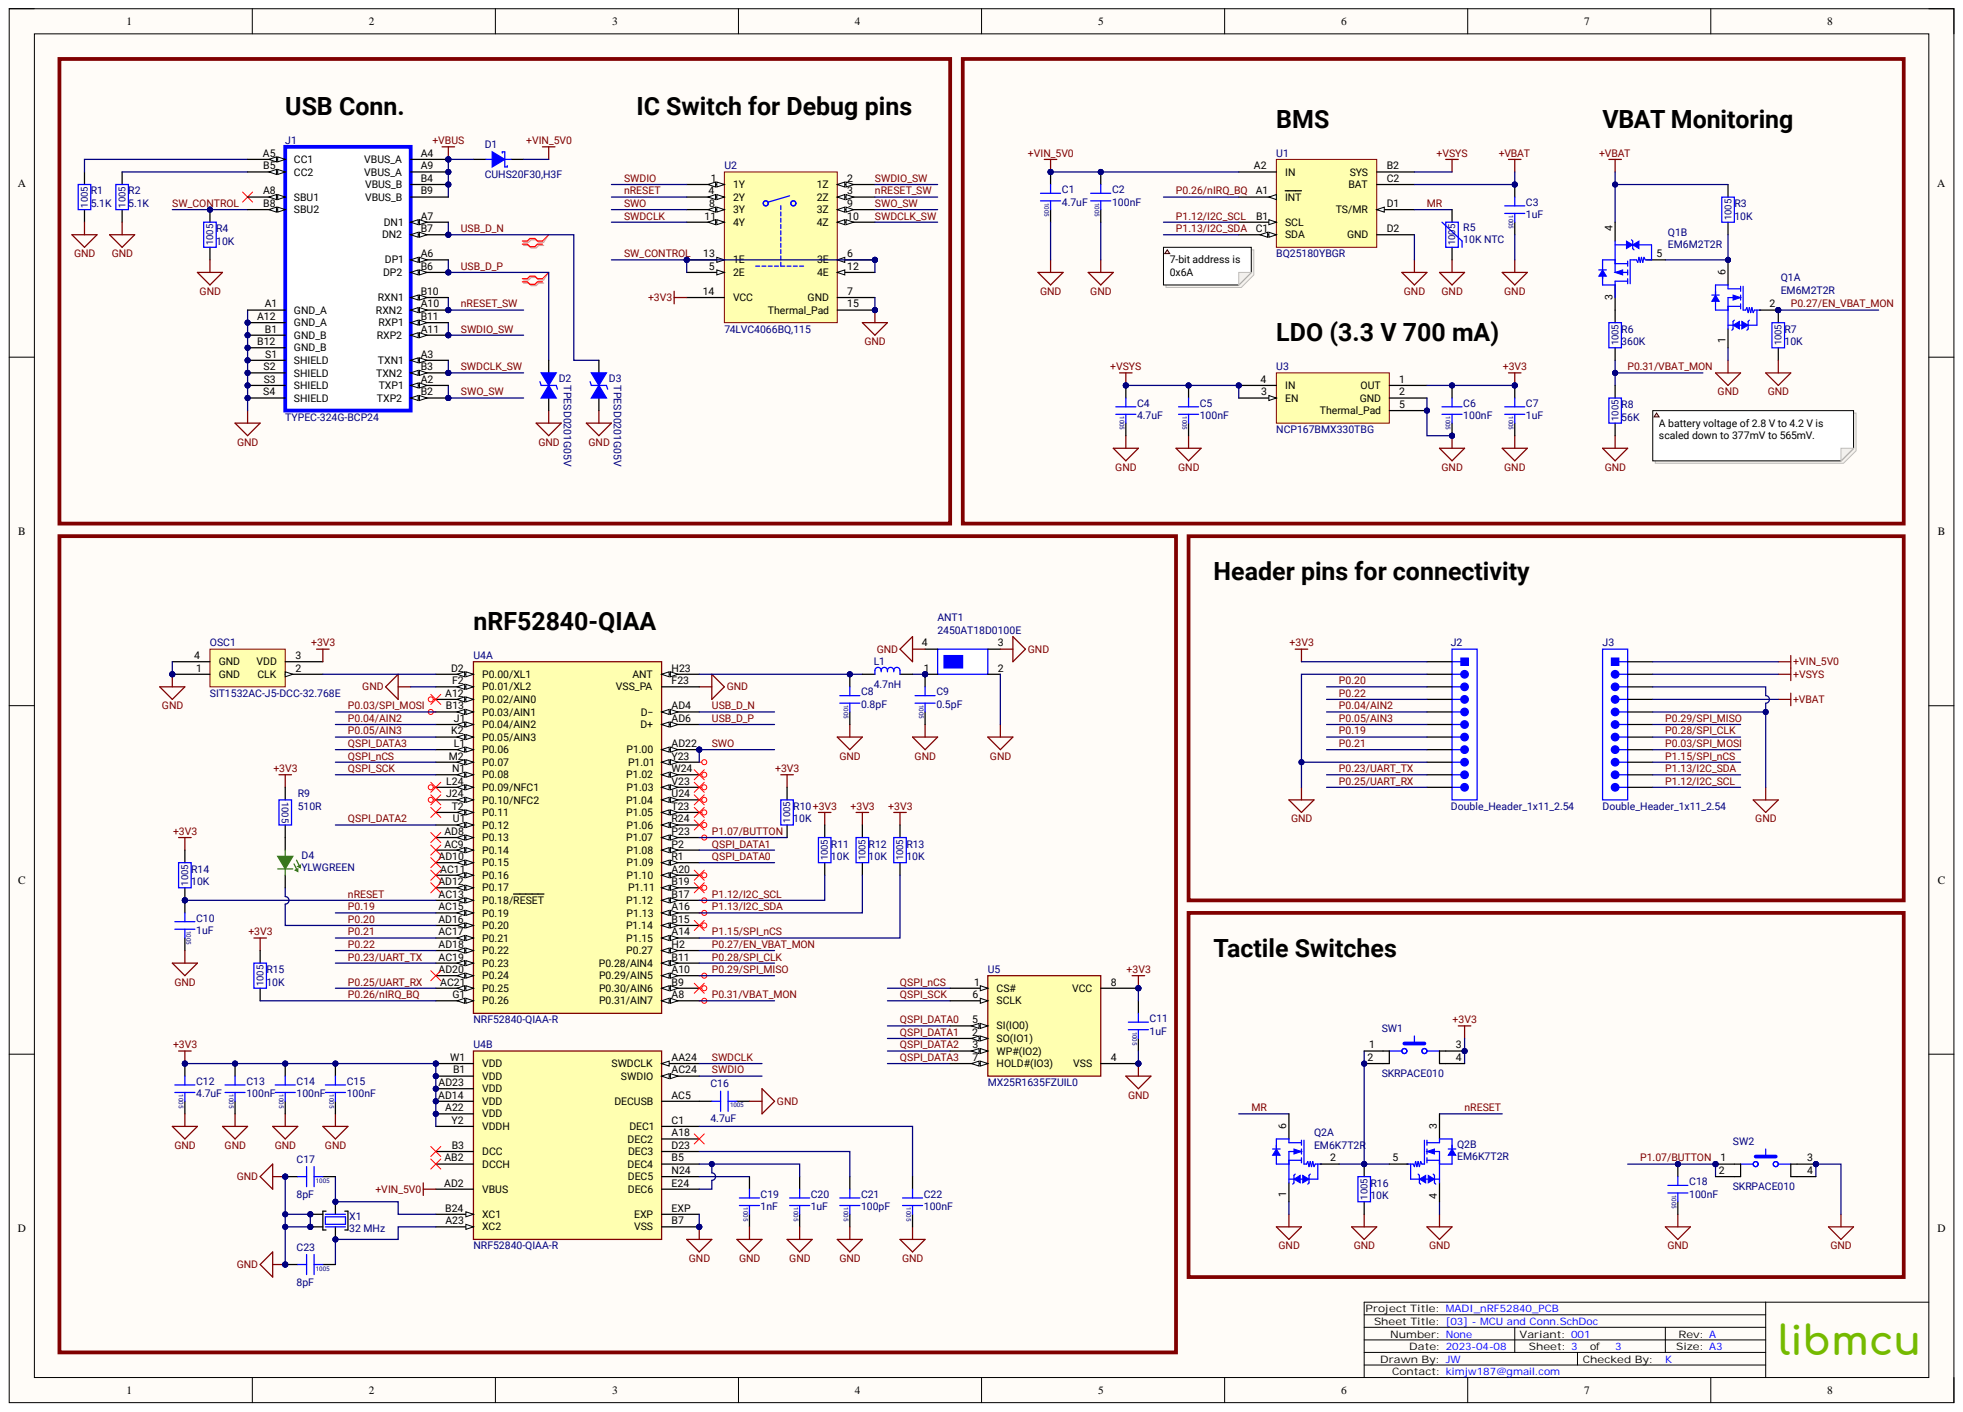
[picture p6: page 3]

A battery voltage of 2.8 V to 4.2 V is
scaled down to 377mV to 565mV.

Header pins for connectivity

P0.17 AD12 | | P1.12/I2C_SCL

P0.19 | | P0.19 AC15 | P1.13/I2C_SDA

C17 | VDD B1 | SWDIO

VDD AD23 | C16 4.7uF

Sheet Title: [03] - MCU and Conn.SchDoc

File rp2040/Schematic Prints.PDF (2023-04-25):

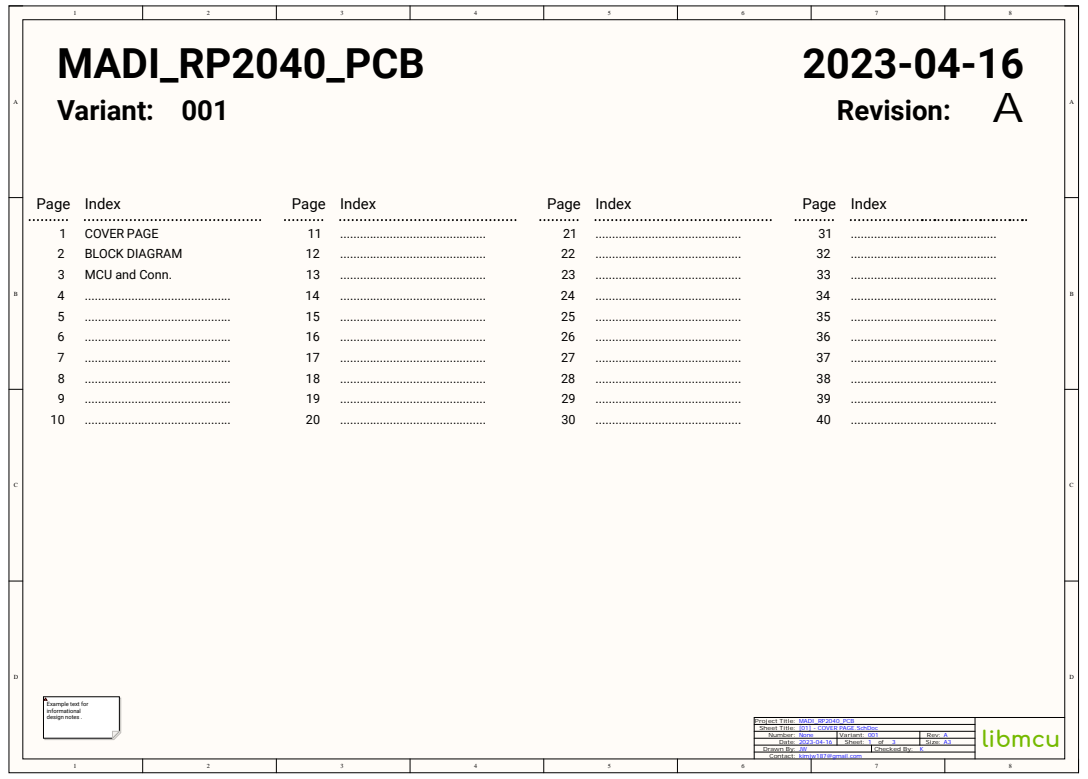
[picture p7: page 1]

Project Title:
Sheet Title: [01] - COVER PAGE.SchDoc

Number: None | Variant: 001 | Rev: A
Date: 2023-04-16 | Sheet: 1 of 3 | Size: A3
Drawn By: JW

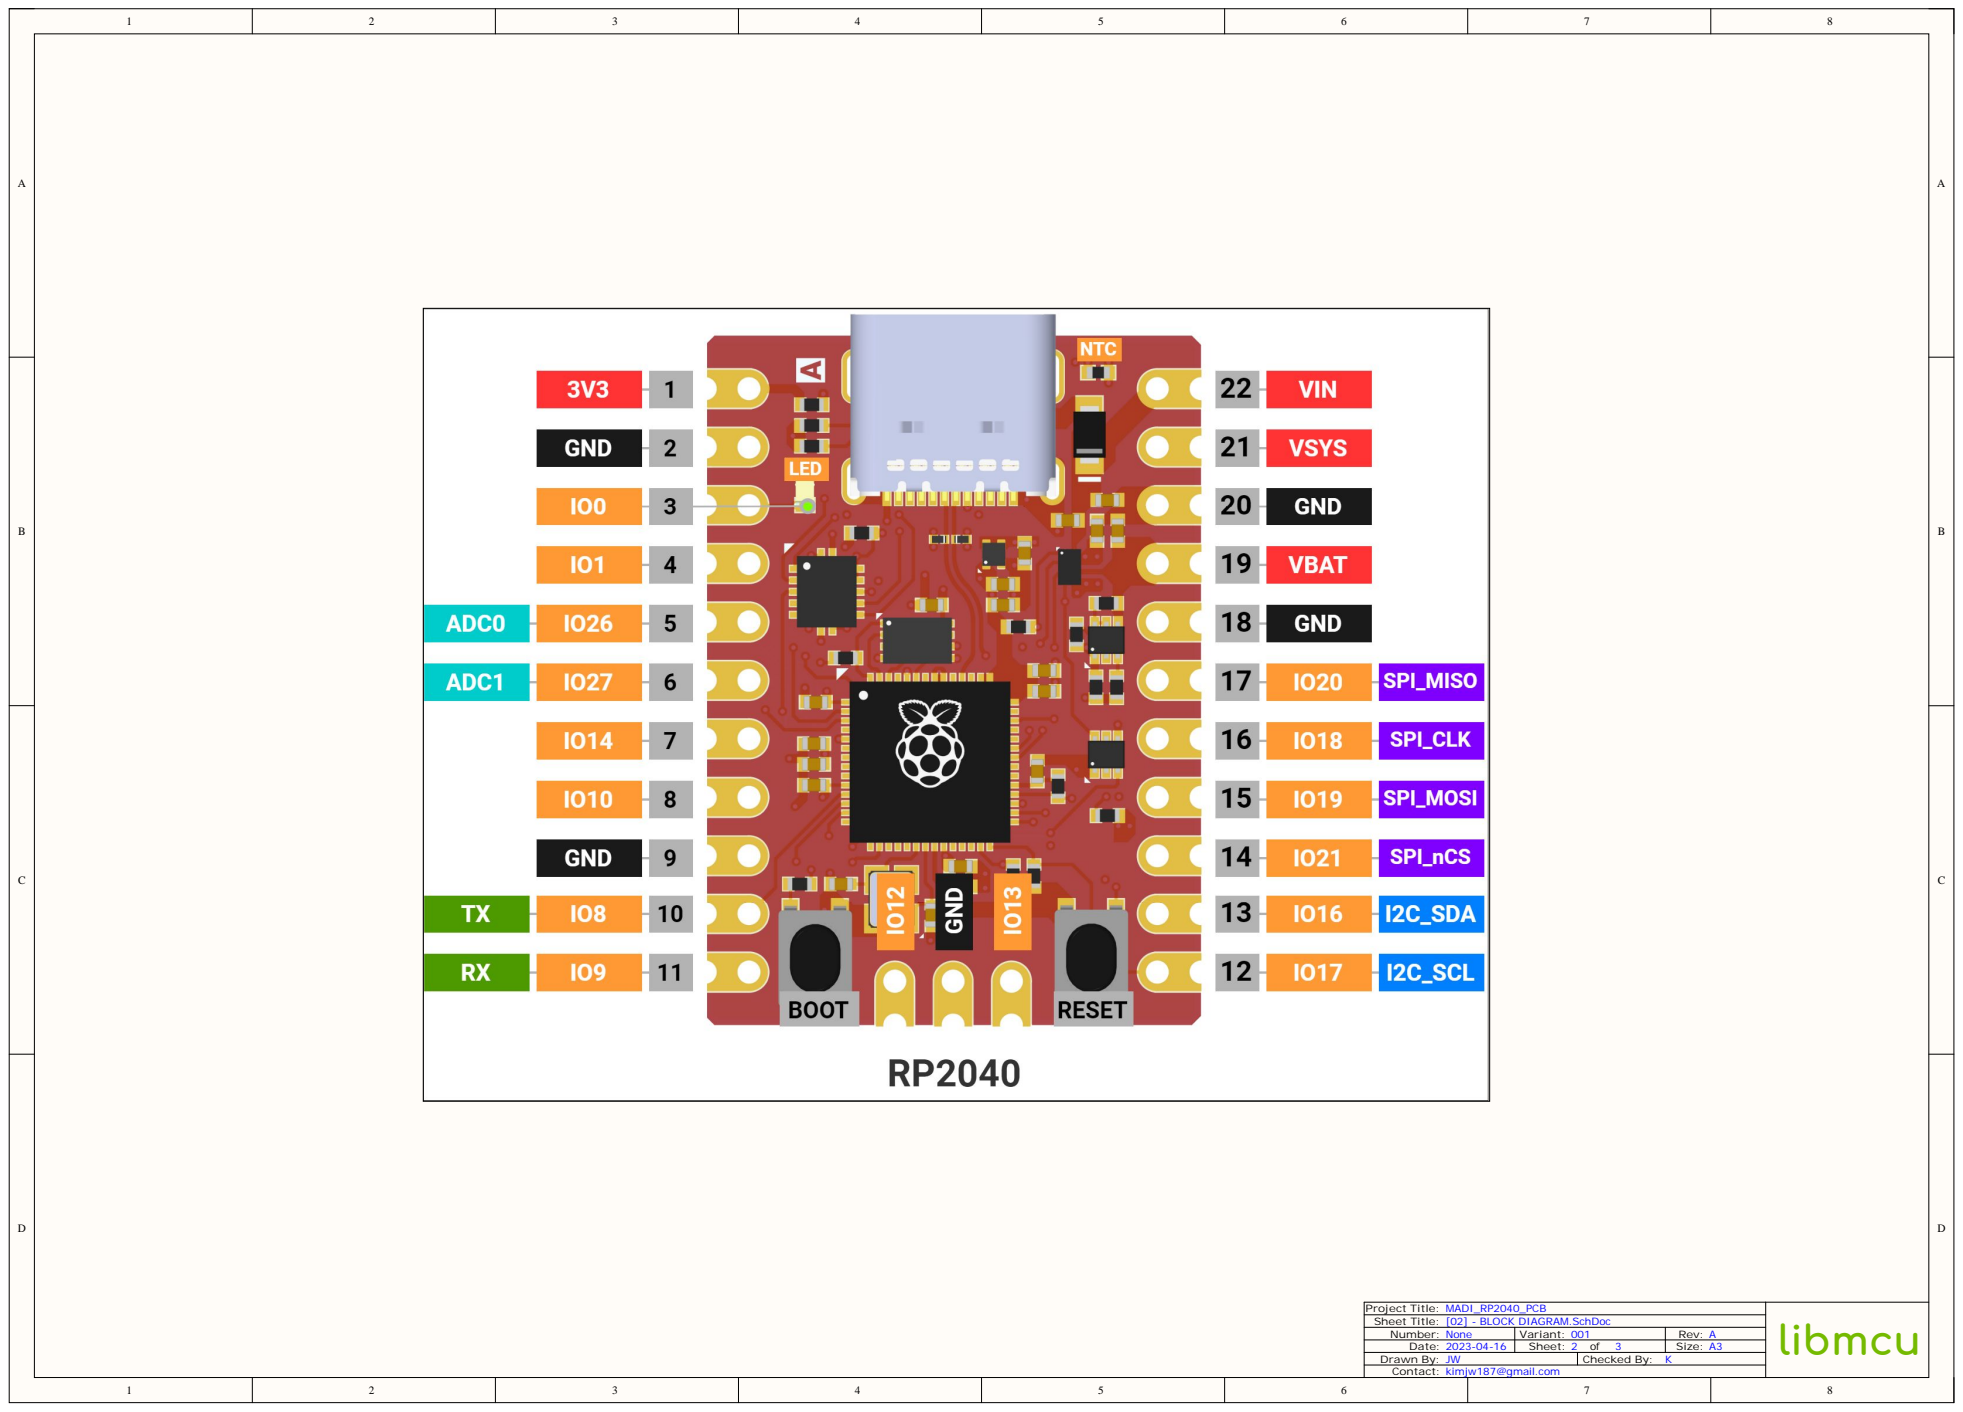
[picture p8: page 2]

Sheet Title: [02] - BLOCK DIAGRAM.SchDoc

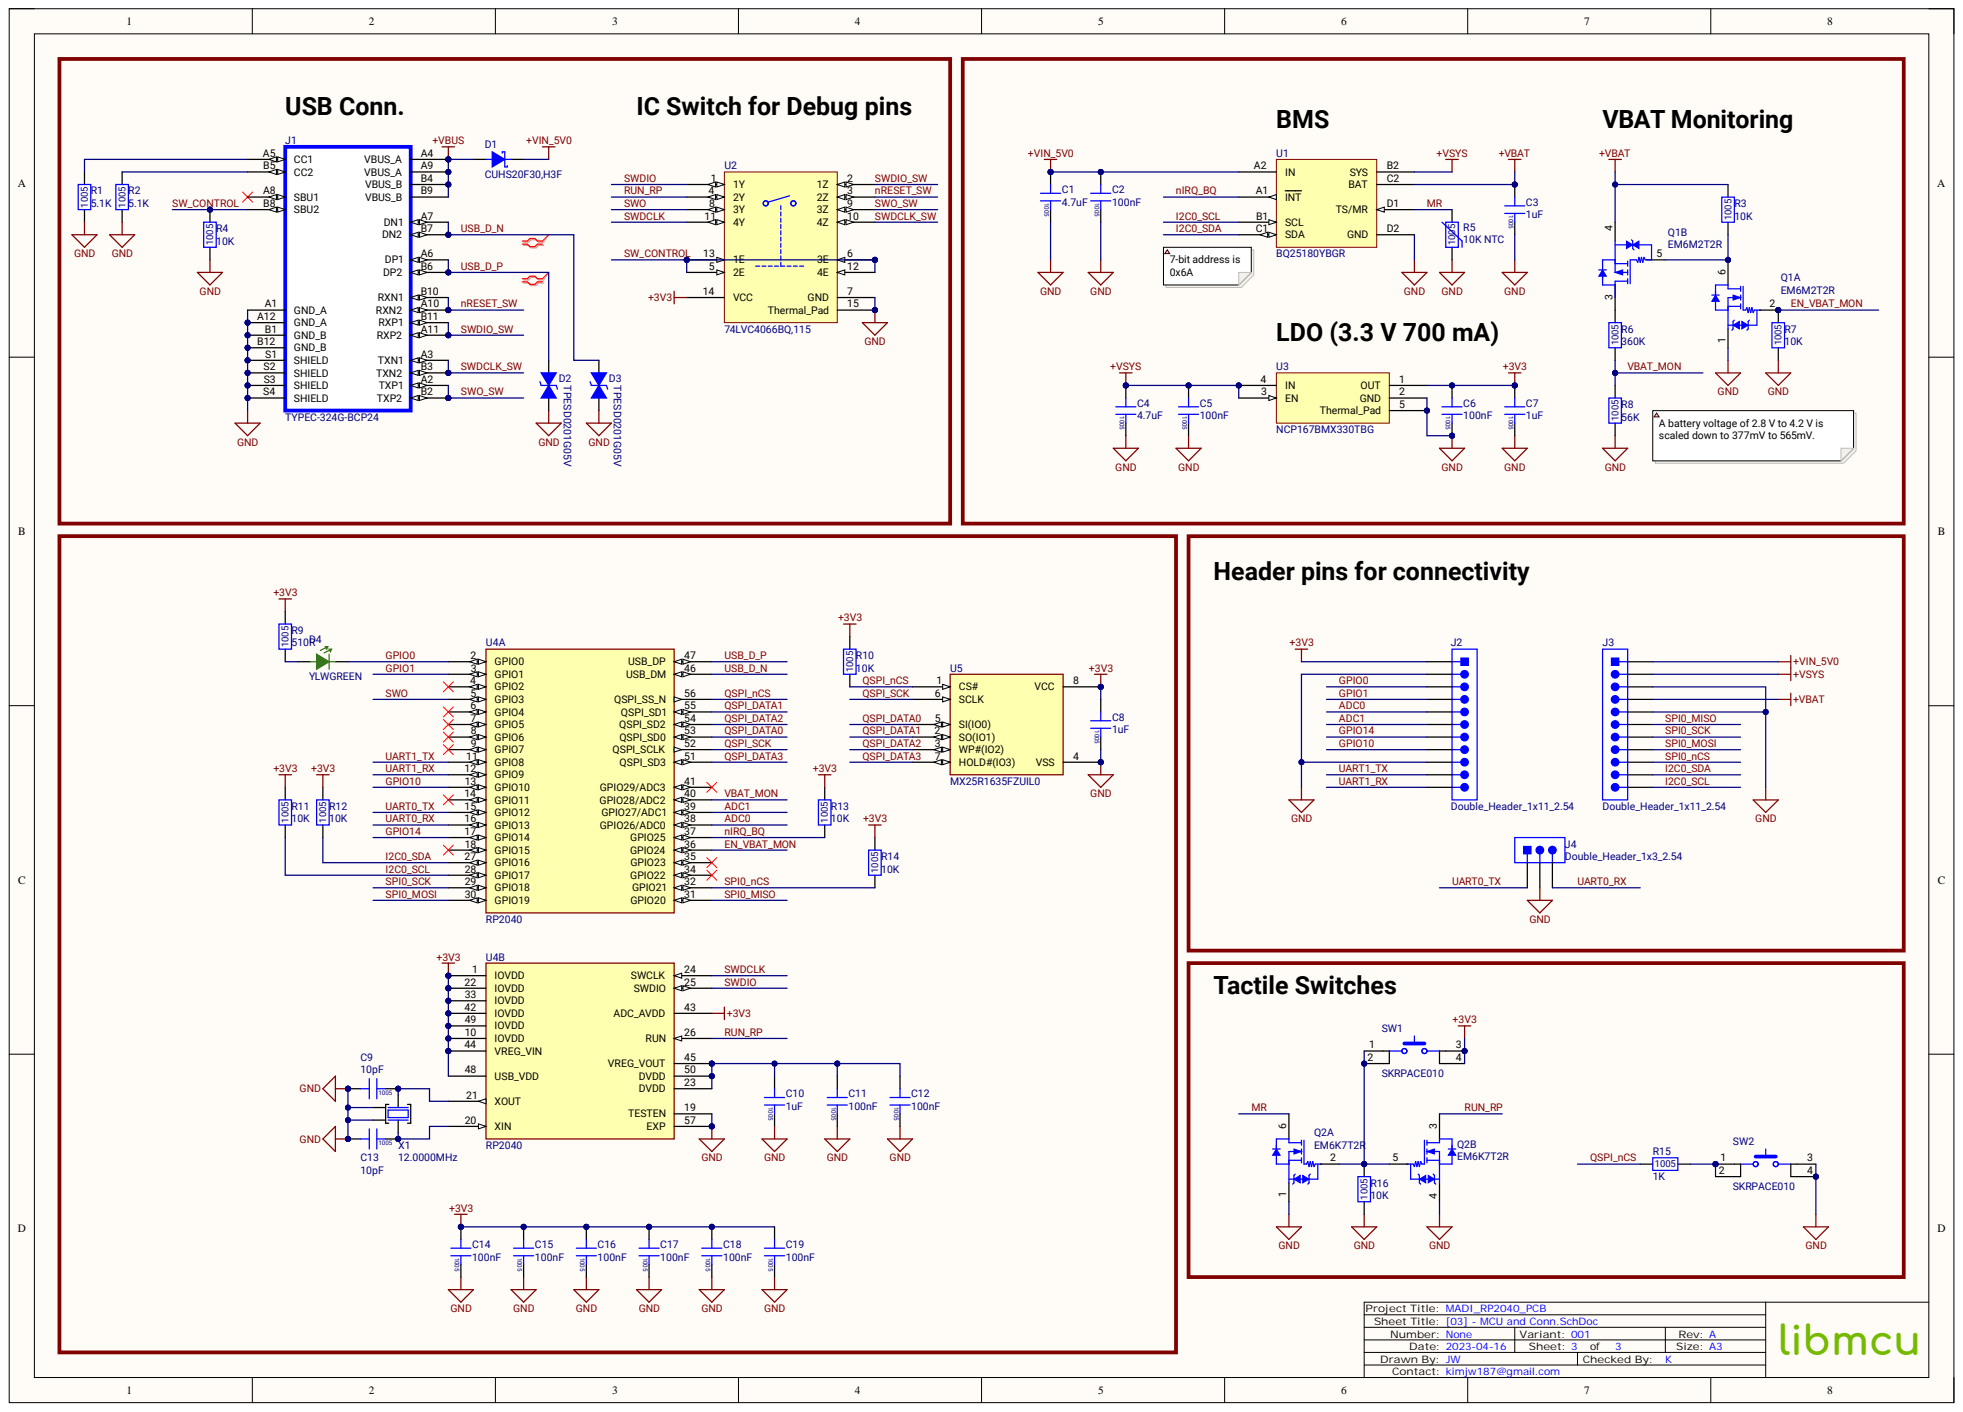
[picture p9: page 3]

A battery voltage of 2.8 V to 4.2 V is
scaled down to 377mV to 565mV.

Header pins for connectivity

Sheet Title: [03] - MCU and Conn.SchDoc

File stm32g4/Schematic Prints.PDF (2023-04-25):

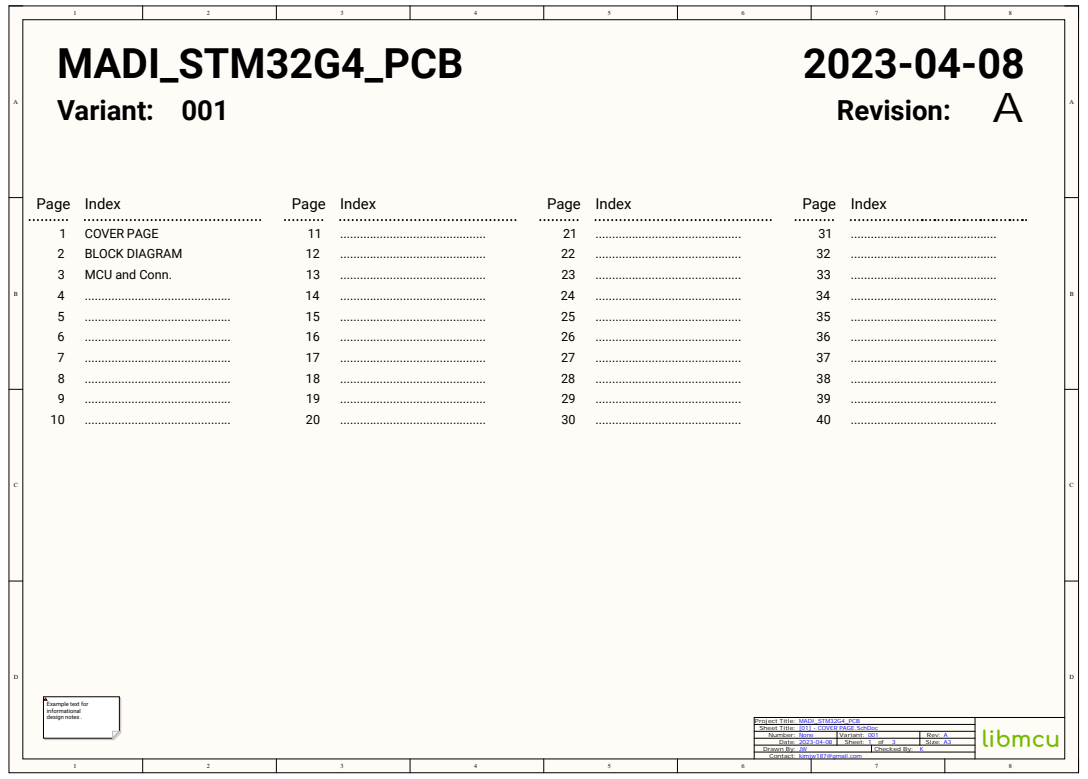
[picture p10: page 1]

Project Title:
Sheet Title: [01] - COVER PAGE.SchDoc

Number: None | Variant: 001 | Rev: A
Date: 2023-04-08 | Sheet: 1 of 3 | Size: A3
Drawn By: JW

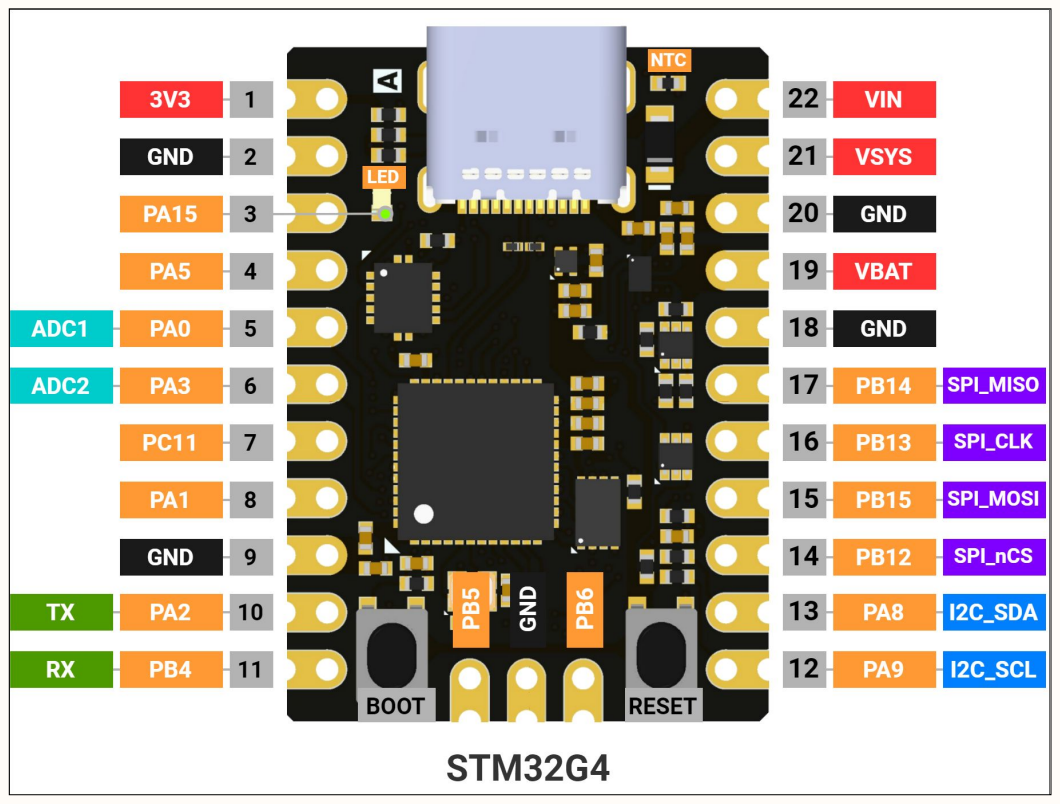
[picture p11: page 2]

Sheet Title: [02] - BLOCK DIAGRAM.SchDoc

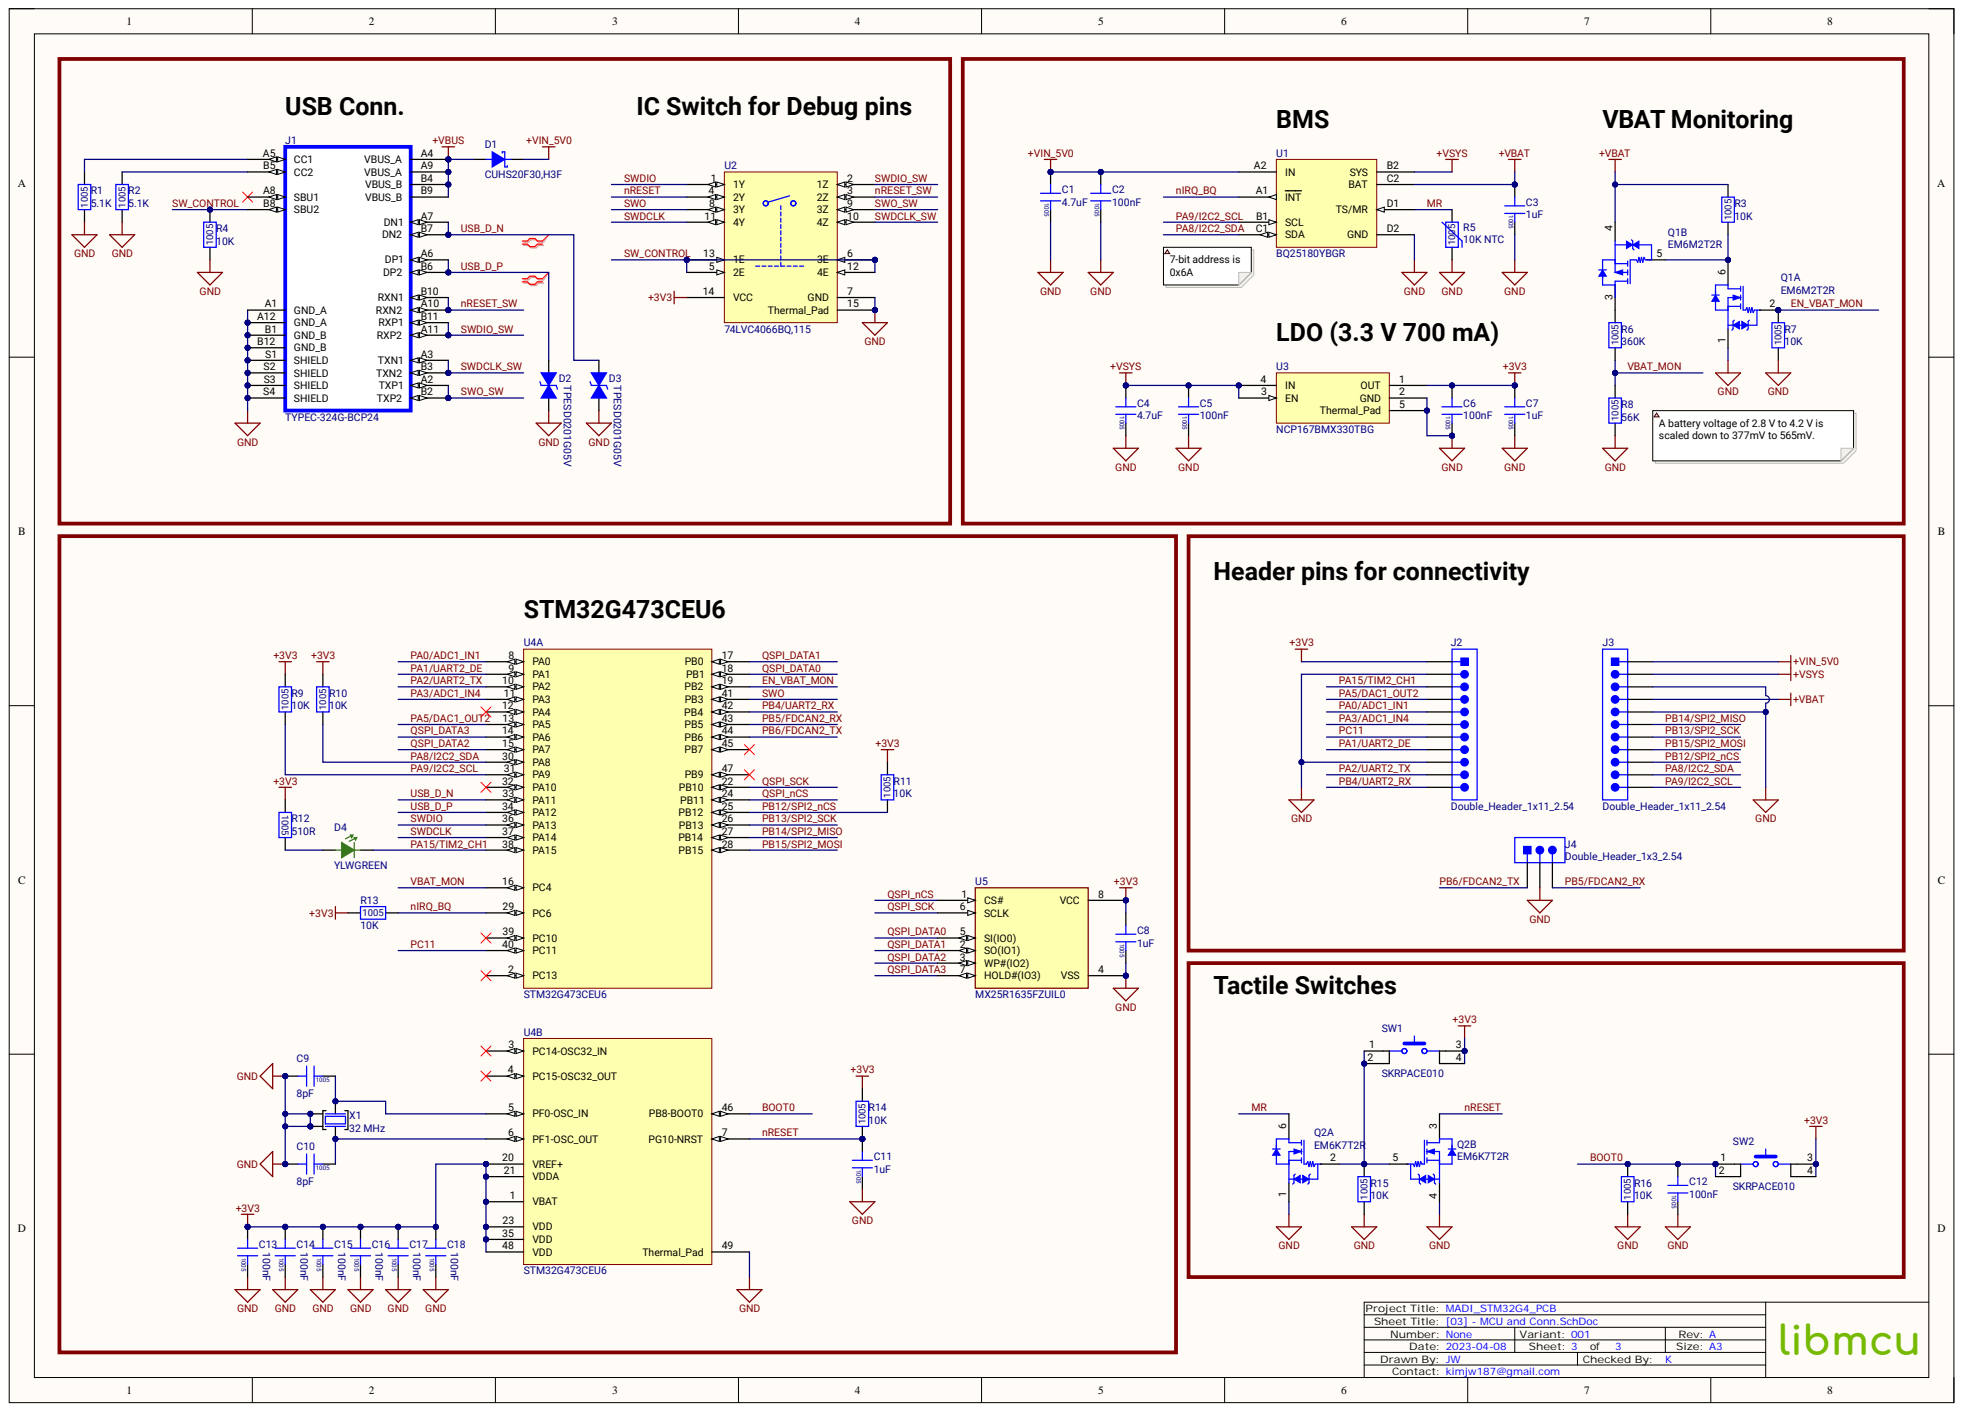
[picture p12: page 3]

A battery voltage of 2.8 V to 4.2 V is
scaled down to 377mV to 565mV.

Header pins for connectivity

Sheet Title: [03] - MCU and Conn.SchDoc

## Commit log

2023-02-12 update schematic and design drawing
2023-03-23 Upload Altium project files
    [MADI_ESP32-S3_PCB.PcbDoc, MADI_ESP32-S3_PCB.PrjPcb, MADI_STM32G4_PCB.PrjPcb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]
2023-04-25 Add a new MADI for RP2040 and update project configuration (#6)
    [MADI_ESP32-S3_PCB.PcbDoc, MADI_RP2040_PCB.PrjPcb, MADI_RP2040_PCB_L4.PcbDoc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]
